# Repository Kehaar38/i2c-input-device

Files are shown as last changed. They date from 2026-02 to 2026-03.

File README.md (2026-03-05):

# I2C Input Device (ATmega328P)

## 概要
- ATmega328P を用いた I2C接続の入力デバイス
- 5ボタン＋ロータリーエンコーダーを搭載
- 差分式エンコーダ出力およびステータスビットを2バイト固定フォーマットで出力
- 動作テスト用デバイスも製作（[Test Device](#Test-Device-XIAO-ESP32S3)）

## 主な機能
- I2Cスレーブ
- 2バイト固定レスポンス
- 差分式エンコーダー

## 出力
I2C 応答フォーマット（Read 2 bytes）
- Byte0: エンコーダー差分（int8_t）
  - 前回 Read 以降の差分
    - -128..127 に飽和（超えたら status=001 を立てる）
    - Read したタイミングで累積差分を 0 にリセット（差分式）

- Byte1: 上位3bit=ステータス, 下位5bit=ボタン押下（押下で1）
  - bit0: center
  - bit1: up
  - bit2: right
  - bit3: down
  - bit4: left
  - status:
    - 000 = 正常
    - 001 = overflow

## ハード構成
- ATmega328P (3.3V, internal 8MHz)
- 5x tactile switch
- 12/15 encoder

## 写真
外観

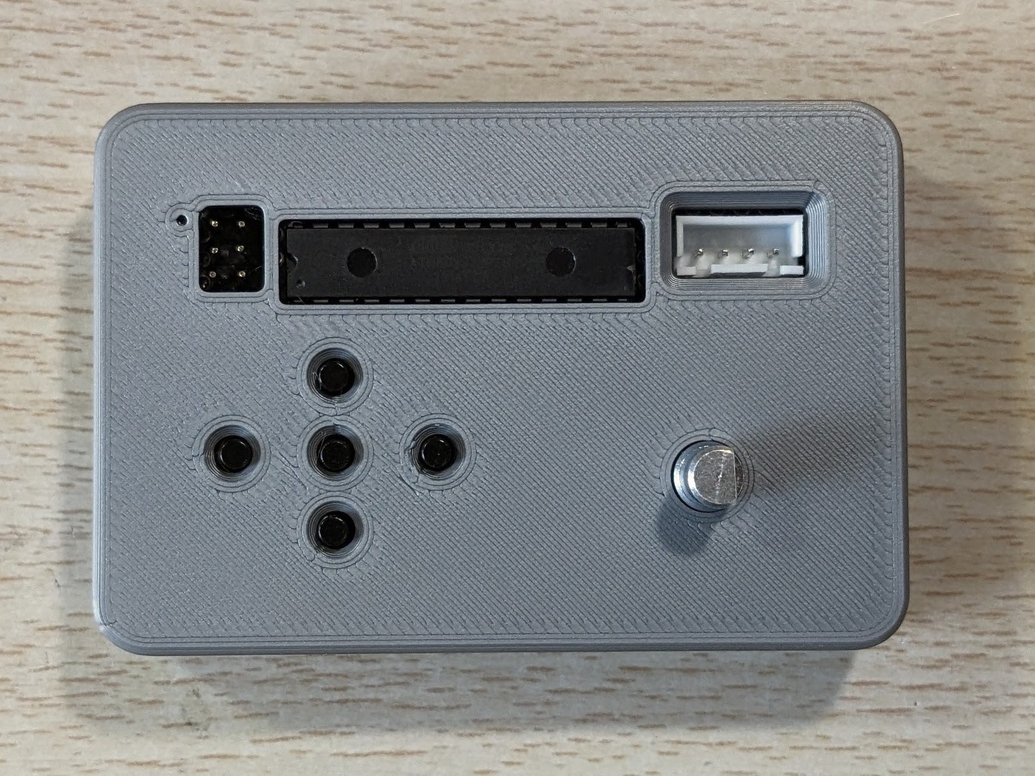
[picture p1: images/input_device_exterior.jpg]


基板

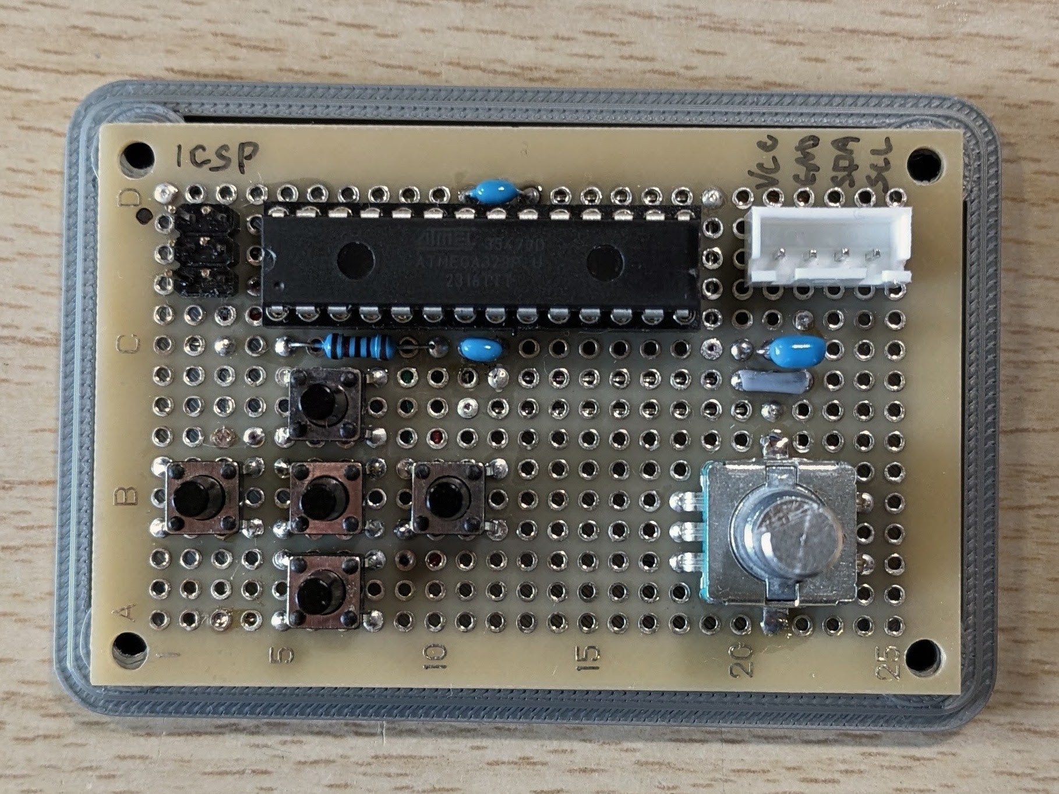
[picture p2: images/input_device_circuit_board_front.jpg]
基板表

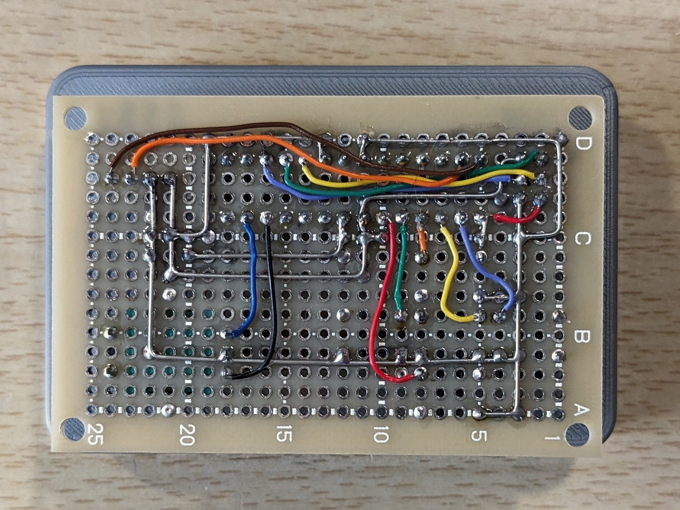
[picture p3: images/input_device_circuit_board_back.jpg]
基板裏


回路図

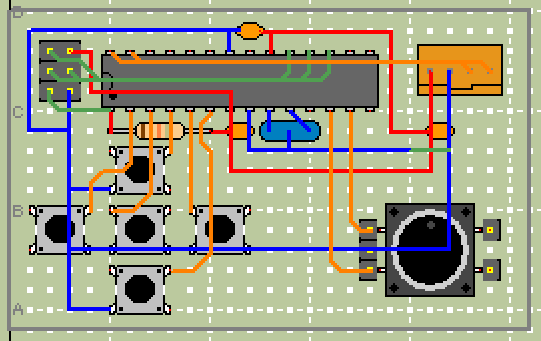
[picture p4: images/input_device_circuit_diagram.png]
回路図


## コーディング
ほぼ全部ChatGPT5.2に書いてもらっています。

## ビルド方法
### 開発環境
- Arduino IDE 2.3.7
- ボードパッケージ: ATmega328（MiniCore）
- 書き込み方式: Arduino as ISP
- ターゲット: ATmega328P（3.3V / 内部8MHz）

### ボード設定
- ボード: ATmega328
- Variant: 328P / 328PA
- Clock: Internal 8 MHz
- Bootloader: No bootloader
- BOD: BOD 2.7V
- EEPROM: EEPROM retained
- Compiler LTO: LTO enabled

### Fuse値
|Fuse|値|意味|
|---|---|---|
|L|E2|内部8MHz、CKDIV8無効|
|H|DA|SPI有効、BOOT無効|
|E|FD|BOD有効|

### I2C動作条件
- 電源: 3.3V
- クロック: 100kHz
- I2Cアドレス: 0x12
- 外部プルアップ抵抗はマスター側に実装

### 補足
- attachInterrupt は使用せず、PCINT を使用している
- onRequest 内で割り込み状態を変更しないこと
- ENC_STEPS_PER_NOTCH はエンコーダ個体に応じて調整すること

### 禁止事項
**書き込み装置とマスターの同時接続は禁止**  
特に書き込み装置とマスターのロジックレベルが異なる場合、電源ラインの逆流やI/Oピンへの過電圧などが生じてデバイスが破損する可能性がある。
- 書き込み時は必ずマスター側を取り外すこと
- 運用時は ISP ケーブルを接続しないこと

---

# Test Device (XIAO ESP32S3)

## 概要
- I2C Input Deviceの出力をテストするデバイス
- ボタンの押下状況とエンコーダーの累積値を表示する

## ハード構成
- XIAO ESP32S3
- 128x64 OLED (SSD1306 Driver)

## コーディング
全部ChatGPT5.2に書いてもらっています。

## 写真
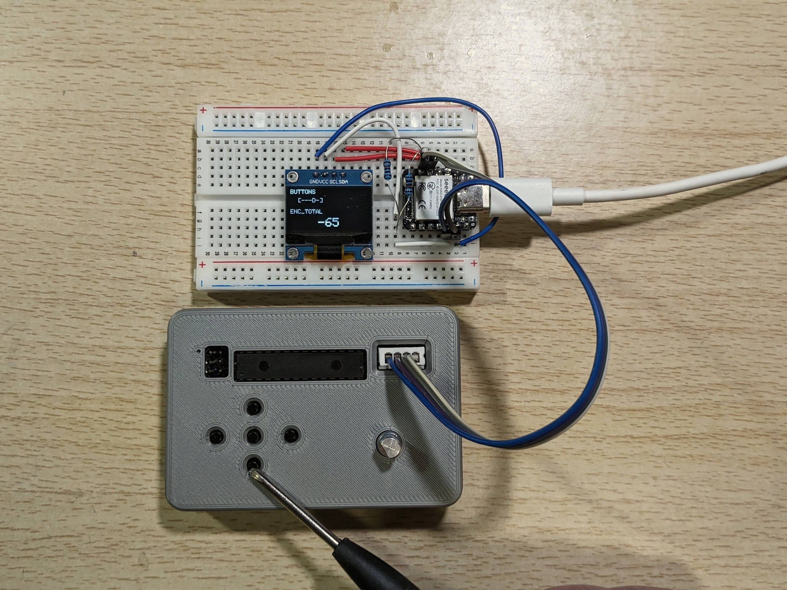
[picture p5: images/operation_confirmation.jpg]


---

## License Notices

Third-party license and notice information is available here:

- `THIRD_PARTY_NOTICES.md`
- `licenses/`

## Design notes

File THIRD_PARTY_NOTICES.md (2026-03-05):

# Third-Party Notices

This repository uses third-party libraries via Arduino cores and Arduino libraries.

## Included notice files

- `licenses/Adafruit_GFX_BSD-2-Clause.txt`
- `licenses/Adafruit_SSD1306_BSD-3-Clause.txt`
- `licenses/Adafruit_BusIO_MIT.txt`
- `licenses/LGPL-2.1.txt`

## Libraries used by this project

### firmware/input_device

- Library: Wire (I2C/TWI)
- Source: Arduino core (MiniCore AVR 3.1.2)
- License: GNU LGPL v2.1 or later (per `Wire.h` header)

### firmware/test_device

- Library: Wire (I2C/TWI)
- Source: ESP32 Arduino core 3.3.7
- License: GNU LGPL v2.1 or later (per `Wire.h` header)

- Library: Adafruit GFX Library 1.12.4
- Source: [Adafruit/Adafruit-GFX-Library](https://github.com/adafruit/Adafruit-GFX-Library)
- License: BSD (see `licenses/Adafruit_GFX_BSD-2-Clause.txt`)

- Library: Adafruit SSD1306 2.5.16
- Source: [Adafruit/Adafruit_SSD1306](https://github.com/adafruit/Adafruit_SSD1306)
- License: BSD (see `licenses/Adafruit_SSD1306_BSD-3-Clause.txt`)

- Dependency: Adafruit BusIO 1.17.4
- Source: [Adafruit/Adafruit_BusIO](https://github.com/adafruit/Adafruit_BusIO)
- License: MIT (see `licenses/Adafruit_BusIO_MIT.txt`)

## Notes

- This repository currently distributes source code and design files; compiled binaries are not distributed.
- If binary distribution starts in the future, include this file and `licenses/` alongside the distributed artifacts.

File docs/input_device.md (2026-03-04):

# ATmega328P (DIP) ピンアサイン
```
                            ATmega328P
                            -----------
    RESET / VCC via R - PC6|1    U   28|PC5 - SCL
             BTN_LEFT - PD0|2        27|PC4 - SDA
           BTN_CENTER - PD1|3        26|PC3 - NC
               BTN_UP - PD2|4        25|PC2 - NC
            BTN_RIGHT - PD3|5        24|PC1 - NC
             BTN_DOWN - PD4|6        23|PC0 - NC
DECAP3 / DECAP1 / VCC - VCC|7        22|GND - GND / DECAP2
DECAP3 / DECAP1 / GND - GND|8        21|AREF - NC
         NC(for XTAL) - PB6|9        20|AVCC - DECAP2
         NC(for XTAL) - PB7|10       19|PB5 - SCK
                   NC - PD5|11       18|PB4 - MISO
                ENC_A - PD6|12       17|PB3 - MOSI
                ENC_B - PD7|13       16|PB2 - NC
                   NC - PB0|14       15|PB1 - NC
                            -----------
```

## 接続
|ピン番号|機能|接続|
|---|---|---|
|1|RESET|PC6 --- J2 --- 10kR --- VCC|
|2|DIGITAL|PD0 --- BTN_LEFT ---GND|
|3|DIGITAL|PD1 --- BTN_CENTER --- GND|
|4|DIGITAL|PD2 --- BTN_UP --- GND|
|5|DIGITAL|PD3 --- BTN_RIGHT --- GND|
|6|DIGITAL|PD4 --- BTN_DOWN --- GND|
|7|VCC|VCC --- (0.1uF to GND) --- (4.7uF to GND) --- J1 --- J2|
|8|GND|GND --- J1 --- J2 --- ENC_C|
|9|(XTAL)|PB6 --- NC|
|10|(XTAL)|PB7 --- NC|
|11|-|PD5 --- NC|
|12|PCINT|PD6 --- ENC_A|
|13|PCINT|PD7 --- ENC_B|
|14|-|PB0 --- NC|
|15|-|PB1 --- NC|
|16|-|PB2 --- NC|
|17|MOSI|PB3 --- J2|
|18|MISO|PB4 --- J2|
|19|SCK|PB5 --- J2|
|20|AVCC|AVCC --- (0.1uF to GND) --- VCC|
|21|-|AREF --- NC|
|22|GND|GND --- GND|
|23|-|PC0 --- NC|
|24|-|PC1 --- NC|
|25|-|PC2 --- NC|
|26|-|PC3 --- NC|
|27|SDA|PC4 --- J1|
|28|SCL|PC5 --- J1|

J1 = マスター接続ピン (VCC, GND, SDA, SCL)  
J2 = ICSPピン

## 配線イメージ
回路図

# 部品リスト
- ATmega328P (DIP)
- ICソケット
- ロータリーエンコーダ
- 5 * タクトスイッチ
- 4.7uF コンデンサ
- 2 * 0.1uF コンデンサ
- 10kΩ 抵抗
- 4ピン JST XH ポスト
- 2x3 ピンヘッダ
- セラロック (任意)
- ユニバーサル基板 秋月Cタイプ

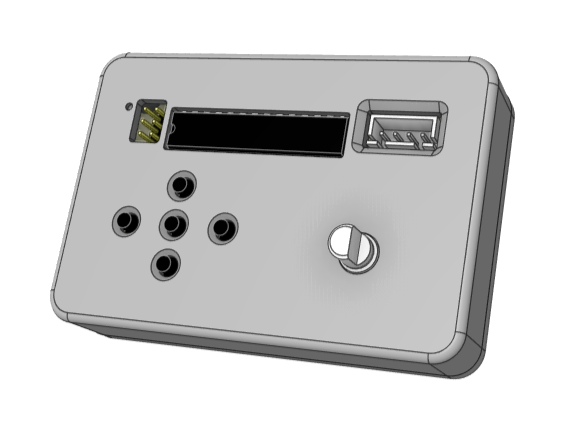
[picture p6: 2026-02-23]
images/input_device_3D_model.png

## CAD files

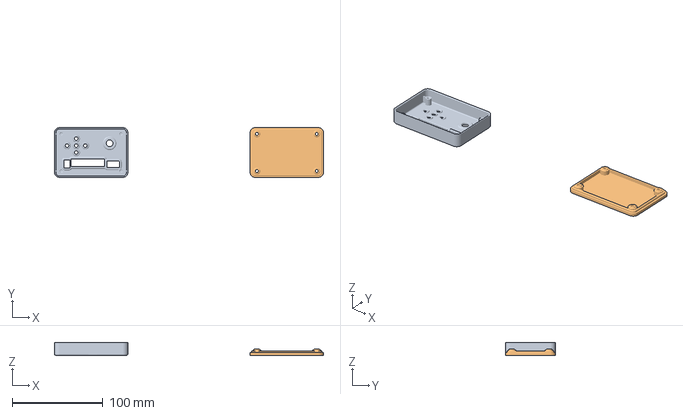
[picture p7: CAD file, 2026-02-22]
hardware/input_device_case/v1.3mf
297.0 x 55.0 x 14.1 mm
アッパーv1.stl
ロワーv1.stl

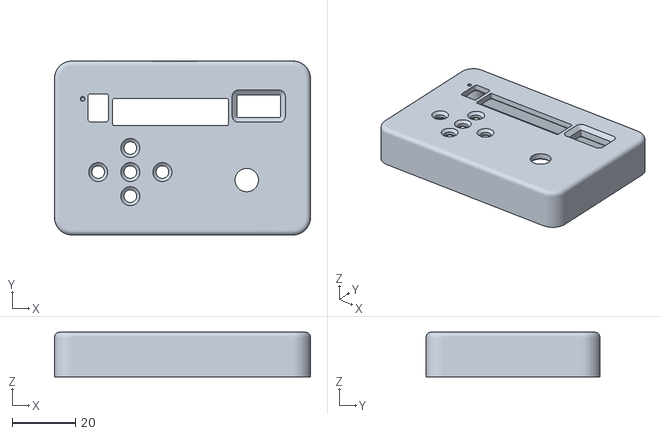
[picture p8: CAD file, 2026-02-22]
hardware/input_device_case/アッパーv1.stl
81.0 x 55.0 x 14.1

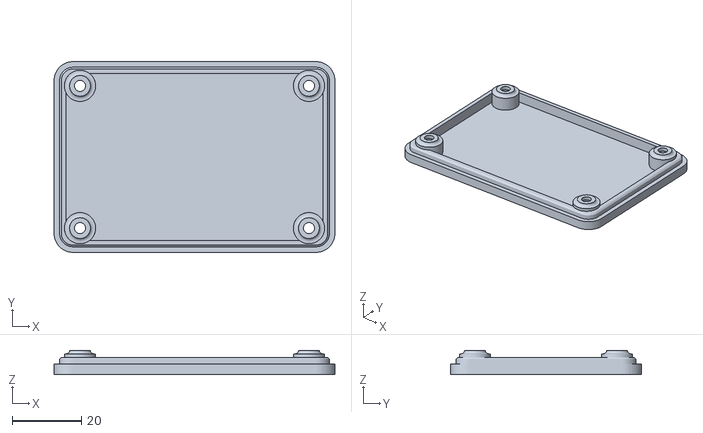
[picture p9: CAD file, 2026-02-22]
hardware/input_device_case/ロワーv1.stl
81.0 x 55.0 x 7.00

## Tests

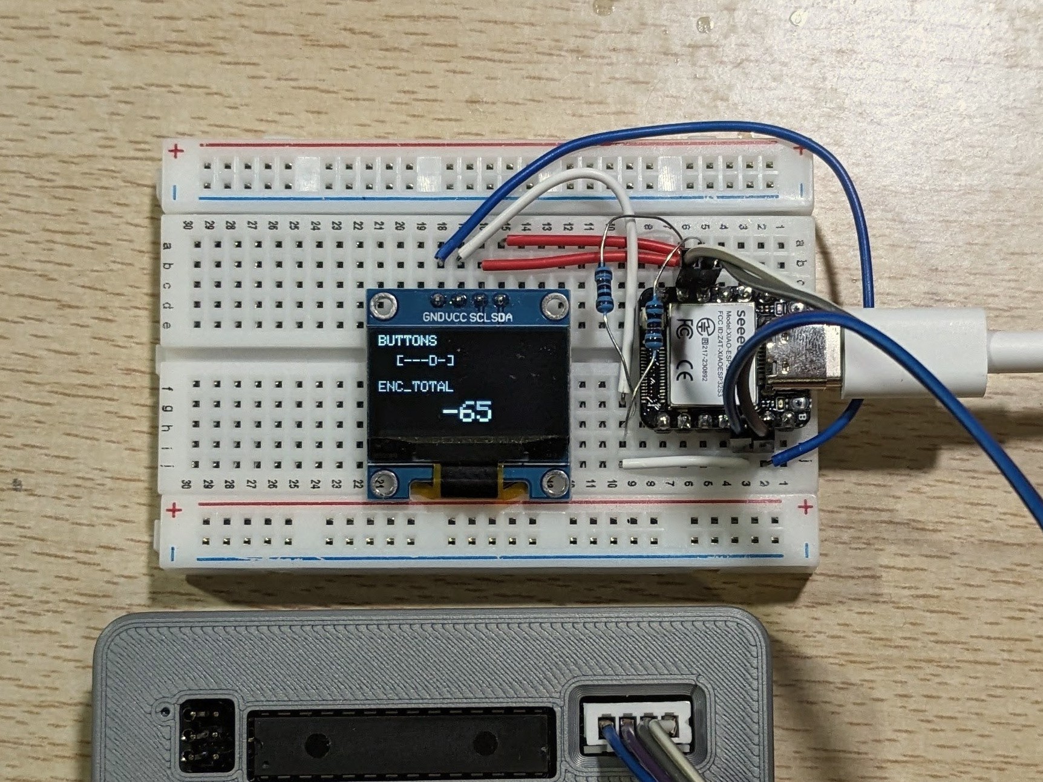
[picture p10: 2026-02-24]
images/test_device_exterior.jpg

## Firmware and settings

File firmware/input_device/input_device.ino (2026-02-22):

/*
  InputDevice (ATmega328P, 3.3V, internal 8MHz)
  - I2C スレーブとして、入力状態を 2バイト固定で返す
  - ボタン 5個 + ロータリーエンコーダ（A/B, スイッチ無し）

  I2C 応答フォーマット（Read 2 bytes）
    Byte0: enc_delta (int8_t)
      - 前回 Read 以降の差分
      - -128..127 に飽和（超えたら status=001 を立てる）
      - Read したタイミングで g_encAcc を 0 にリセット（差分式）

    Byte1: 上位3bit=status, 下位5bit=buttons
      bit0: center
      bit1: up
      bit2: right
      bit3: down
      bit4: left
      status:
        000 = 正常
        001 = overflow（飽和/内部飽和などの異常を検出）
*/

#include <Arduino.h>
#include <Wire.h>

#include <util/atomic.h>
#include <avr/interrupt.h>

// ================================
// ユーザー設定
// ================================
static const uint8_t I2C_ADDR = 0x12;

// ボタン（INPUT_PULLUP）
// 物理的には「押すとGNDへ落ちる」
// 出力（ビットマスク）は「押下=1」に揃える
static const uint8_t PIN_BTN_CENTER = PD1;
static const uint8_t PIN_BTN_UP     = PD2;
static const uint8_t PIN_BTN_RIGHT  = PD3;
static const uint8_t PIN_BTN_DOWN   = PD4;
static const uint8_t PIN_BTN_LEFT   = PD0;

// エンコーダ（A/B, INPUT_PULLUP）
static const uint8_t PIN_ENC_A = PD6; // PCINT22
static const uint8_t PIN_ENC_B = PD7; // PCINT23

// 1クリック（カチッ）あたりの「有効遷移数」
// エンコーダ個体によって 1/2/4 等があるので、実測で合わせる。
static const int8_t ENC_STEPS_PER_NOTCH = 2;

// 右回りを + にしたい場合 true（符号反転）
// もし逆だったら false にするだけでOK
static const bool ENC_DIR_REVERSE = true;

// ボタンのサンプリング周期（ms）
static const uint16_t BTN_SAMPLE_MS = 1;

// ================================
// 共有状態（ISR + I2C）
// ================================
// エンコーダ：差分累積（Readしたら0にリセット）
volatile int16_t g_encAcc = 0;

// エンコーダ：クリック換算前の途中経過（クォドラチャステップ）
// ※ これを I2C Read 毎に 0 にすると、ゆっくり回した時に反応しなくなるので保持する
volatile int8_t g_qstepAcc = 0;

// status（3bit）: 000=OK, 001=overflow
volatile uint8_t g_status3 = 0;

// ボタン（5bit, 押下=1）
volatile uint8_t g_btnMask5 = 0;

// ================================
// ヘルパ
// ================================
static inline void set_overflow_flag() {
  g_status3 = 0x01; // 001
}

static inline int8_t clamp_i16_to_i8(int16_t v, bool &clamped) {
  if (v > 127)  { clamped = true; return 127; }
  if (v < -128) { clamped = true; return -128; }
  clamped = false;
  return (int8_t)v;
}

// g_encAcc を int16 範囲で飽和加算（wrap防止）
static inline void encAcc_add_saturating(int16_t delta) {
  int32_t tmp = (int32_t)g_encAcc + (int32_t)delta;
  if (tmp > 32767) {
    g_encAcc = 32767;
    set_overflow_flag();
  } else if (tmp < -32768) {
    g_encAcc = -32768;
    set_overflow_flag();
  } else {
    g_encAcc = (int16_t)tmp;
  }
}

// ================================
// エンコーダ：クォドラチャデコード（PCINT）
// ================================
volatile uint8_t g_prevAB = 0;

static inline uint8_t readAB() {
  uint8_t a = (uint8_t)digitalRead(PIN_ENC_A);
  uint8_t b = (uint8_t)digitalRead(PIN_ENC_B);
  return (uint8_t)((a << 1) | b);
}

// A/Bの状態遷移から +1/-1 のクォドラチャステップを生成する
// 不正遷移（チャタ/ノイズ）は 0 扱いで捨てる
static inline int8_t quadrature_step(uint8_t prevAB, uint8_t currAB) {
  const uint8_t t = (uint8_t)((prevAB << 2) | currAB);

  // 0..15 の遷移に対するステップ（標準Gray系列前提）
  static const int8_t stepTable[16] = {
     0, -1, +1,  0,
    +1,  0,  0, -1,
    -1,  0,  0, +1,
     0, +1, -1,  0
  };

  int8_t s = stepTable[t];

  // 回転方向の符号を反転（右回りを + に合わせたい時に使う）
  if (ENC_DIR_REVERSE) s = (int8_t)-s;

  return s;
}

// PCINTが来たらA/B変化を1回処理する
void isr_encoder_change() {
  const uint8_t curr = readAB();
  const uint8_t prev = g_prevAB;
  g_prevAB = curr;

  int8_t qstep = quadrature_step(prev, curr);
  if (qstep == 0) return;

  // クリック換算用にクォドラチャステップを累積
  g_qstepAcc = (int8_t)(g_qstepAcc + qstep);

  // クリック単位（±1）へ変換
  if (ENC_STEPS_PER_NOTCH > 0) {
    while (g_qstepAcc >= ENC_STEPS_PER_NOTCH) {
      g_qstepAcc -= ENC_STEPS_PER_NOTCH;
      encAcc_add_saturating(+1);
    }
    while (g_qstepAcc <= -ENC_STEPS_PER_NOTCH) {
      g_qstepAcc += ENC_STEPS_PER_NOTCH;
      encAcc_add_saturating(-1);
    }
  }
}

// Port D（PCINT[23:16]）のピン変化割り込み
ISR(PCINT2_vect) {
  isr_encoder_change();
}

// ================================
// ボタン：簡易デバウンス（8サンプルのシフトレジスタ）
// ================================
struct Debounce8 {
  uint8_t hist = 0xFF;      // pullup=1 なので未押下を 1 とする
  bool stablePressed = false;

  void update(bool pinHigh) {
    hist = (uint8_t)((hist << 1) | (pinHigh ? 1 : 0));
    if (hist == 0x00) stablePressed = true;   // 連続0 -> 押下安定
    else if (hist == 0xFF) stablePressed = false; // 連続1 -> 未押下安定
  }
};

Debounce8 db_center, db_up, db_right, db_down, db_left;

// 押下状態を 5bit にパック（押下=1）
static inline uint8_t packButtons5() {
  uint8_t m = 0;
  if (db_center.stablePressed) m |= (1 << 0);
  if (db_up.stablePressed)     m |= (1 << 1);
  if (db_right.stablePressed)  m |= (1 << 2);
  if (db_down.stablePressed)   m |= (1 << 3);
  if (db_left.stablePressed)   m |= (1 << 4);
  return m;
}

static inline void updateButtonsDebounced() {
  db_center.update(digitalRead(PIN_BTN_CENTER));
  db_up.update(digitalRead(PIN_BTN_UP));
  db_right.update(digitalRead(PIN_BTN_RIGHT));
  db_down.update(digitalRead(PIN_BTN_DOWN));
  db_left.update(digitalRead(PIN_BTN_LEFT));

  const uint8_t m = packButtons5();

  // g_btnMask5 はISRからも参照され得るので、原子更新にする
  ATOMIC_BLOCK(ATOMIC_RESTORESTATE) {
    g_btnMask5 = m;
  }
}

// ================================
// I2C：Read要求が来たら 2バイト返す
// ================================
void onI2CRequest() {
  int16_t encSnap;
  uint8_t btnSnap;
  uint8_t stSnap;

  // 共有変数をスナップショットし、必要なものだけクリアする
  ATOMIC_BLOCK(ATOMIC_RESTORESTATE) {
    encSnap = g_encAcc;
    g_encAcc = 0;     // 差分式：読んだら0にする
    // g_qstepAcc は保持（途中経過を捨てない）
    btnSnap = g_btnMask5;
    stSnap  = g_status3;
    g_status3 = 0;    // statusは読んだらクリア（必要なら保持方式に変更可）
  }

  // encSnap を int8 に飽和
  bool clamped = false;
  int8_t encOut = clamp_i16_to_i8(encSnap, clamped);
  if (clamped) stSnap = 0x01; // overflow

  const uint8_t out0 = (uint8_t)encOut;
  const uint8_t out1 = (uint8_t)(((stSnap & 0x07) << 5) | (btnSnap & 0x1F));

  Wire.write(out0);
  Wire.write(out1);
}

// ================================
// setup / loop
// ================================
uint32_t lastBtnMs = 0;

void setup() {
  // ボタン入力
  pinMode(PIN_BTN_CENTER, INPUT_PULLUP);
  pinMode(PIN_BTN_UP,     INPUT_PULLUP);
  pinMode(PIN_BTN_RIGHT,  INPUT_PULLUP);
  pinMode(PIN_BTN_DOWN,   INPUT_PULLUP);
  pinMode(PIN_BTN_LEFT,   INPUT_PULLUP);

  // エンコーダ入力
  pinMode(PIN_ENC_A, INPUT_PULLUP);
  pinMode(PIN_ENC_B, INPUT_PULLUP);
  g_prevAB = readAB();

  // PCINT（Port D）を有効化：PD6/PD7（PCINT22/23）
  PCICR  |= (1 << PCIE2);
  PCMSK2 |= (1 << PCINT22);
  PCMSK2 |= (1 << PCINT23);

  // I2Cスレーブ開始
  Wire.begin(I2C_ADDR);
  Wire.onRequest(onI2CRequest);

  // デバウンス初期化（短時間で安定状態に寄せる）
  for (int i = 0; i < 16; i++) {
    updateButtonsDebounced();
    delay(1);
  }
  lastBtnMs = millis();
}

void loop() {
  // ボタンは一定周期で更新
  const uint32_t now = millis();
  if ((uint32_t)(now - lastBtnMs) >= BTN_SAMPLE_MS) {
    lastBtnMs = now;
    updateButtonsDebounced();
  }
}

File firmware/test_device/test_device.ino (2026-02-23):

#include <Wire.h>
#include <Adafruit_GFX.h>
#include <Adafruit_SSD1306.h>

// ================================
// I2C Config
// ================================
static const uint8_t I2C_ADDR_INPUT = 0x12;     // InputDevice (ATmega) I2C address
static const uint8_t I2C_ADDR_OLED  = 0x3C;     // SSD1306 OLED address

static const int I2C_SDA_PIN = 5;               // XIAO ESP32-S3 D4 = GPIO5
static const int I2C_SCL_PIN = 6;               // XIAO ESP32-S3 D5 = GPIO6
static const uint32_t I2C_FREQ = 100000;        // 100kHz

// Polling interval
static const uint32_t POLL_MS = 50;

// ================================
// OLED Config
// ================================
#define SCREEN_WIDTH  128
#define SCREEN_HEIGHT 64
#define OLED_RESET    -1
Adafruit_SSD1306 display(SCREEN_WIDTH, SCREEN_HEIGHT, &Wire, OLED_RESET);

// OLED更新周期（頻繁に更新しすぎるとちらつくので控えめに）
static const uint32_t OLED_UPDATE_MS = 100;

// ================================
// Protocol / Buttons
// Byte1 low 5 bits = buttons (pressed=1)
// bit0:center, bit1:up, bit2:right, bit3:down, bit4:left
// Byte1 high 3 bits = status (000 OK, 001 OVF)
// ================================
enum ButtonBits : uint8_t {
  BTN_CENTER = 1 << 0,
  BTN_UP     = 1 << 1,
  BTN_RIGHT  = 1 << 2,
  BTN_DOWN   = 1 << 3,
  BTN_LEFT   = 1 << 4,
};

// 長押し判定（ms）
static const uint32_t LONG_PRESS_MS = 800;

// ================================
// Helpers (Serial)
// ================================
static void printButtons(uint8_t b5) {
  Serial.print("buttons[");
  Serial.print((b5 & BTN_CENTER) ? "C" : "-");
  Serial.print((b5 & BTN_UP)     ? "U" : "-");
  Serial.print((b5 & BTN_RIGHT)  ? "R" : "-");
  Serial.print((b5 & BTN_DOWN)   ? "D" : "-");
  Serial.print((b5 & BTN_LEFT)   ? "L" : "-");
  Serial.print("] ");
}

static void printBinary5(uint8_t b5) {
  for (int i = 4; i >= 0; --i) Serial.print((b5 >> i) & 1);
}

static void printStatus(uint8_t st3) {
  Serial.print("status=");
  Serial.print(st3, DEC);
  if (st3 == 0) Serial.print("(OK)");
  else if (st3 == 1) Serial.print("(OVF)");
  else Serial.print("(UNK)");
}

// ================================
// Helpers (OLED)
// ================================
static void makeButtonsString(char out[8], uint8_t b5) {
  // 表示例: [--R--]
  // 並び: C U R D L
  out[0] = '[';
  out[1] = (b5 & BTN_CENTER) ? 'C' : '-';
  out[2] = (b5 & BTN_UP)     ? 'U' : '-';
  out[3] = (b5 & BTN_RIGHT)  ? 'R' : '-';
  out[4] = (b5 & BTN_DOWN)   ? 'D' : '-';
  out[5] = (b5 & BTN_LEFT)   ? 'L' : '-';
  out[6] = ']';
  out[7] = '\0';
}

static void drawCenteredText(int16_t y, const String &text, uint8_t textSize) {
  display.setTextSize(textSize);
  display.setTextColor(SSD1306_WHITE);

  int16_t x1, y1;
  uint16_t w, h;
  display.getTextBounds(text, 0, y, &x1, &y1, &w, &h);
  int16_t x = (SCREEN_WIDTH - (int16_t)w) / 2;
  if (x < 0) x = 0;
  display.setCursor(x, y);
  display.print(text);
}

static void updateOLED(uint8_t buttons5, int32_t encTotal) {
  char btnStr[8];
  makeButtonsString(btnStr, buttons5);

  display.clearDisplay();

  // 見出し
  display.setTextSize(1);
  display.setTextColor(SSD1306_WHITE);

  display.setCursor(0, 0);
  display.println("BUTTONS");

  display.setCursor(0, 14);
  display.print("  ");
  display.println(btnStr);

  display.setCursor(0, 32);
  display.println("ENC_TOTAL");

  // 数値は中央に大きめで表示
  drawCenteredText(46, String(encTotal), 2);

  display.display();
}

// ================================
// Main
// ================================
void setup() {
  Serial.begin(115200);
  delay(300);

  Serial.println();
  Serial.println("InputDevice I2C Reader (XIAO ESP32-S3)");
  Serial.println("Reading 2 bytes: [enc_delta(int8), status3+buttons5]");
  Serial.printf("I2C(Input)=0x%02X  OLED=0x%02X  SDA(GPIO%d) SCL(GPIO%d) freq=%lu\n",
                I2C_ADDR_INPUT, I2C_ADDR_OLED, I2C_SDA_PIN, I2C_SCL_PIN, (unsigned long)I2C_FREQ);

  Wire.begin(I2C_SDA_PIN, I2C_SCL_PIN);
  Wire.setClock(I2C_FREQ);

  // OLED init
  if (!display.begin(SSD1306_SWITCHCAPVCC, I2C_ADDR_OLED)) {
    Serial.println("SSD1306 allocation failed");
    while (true) delay(100);
  }
  display.clearDisplay();
  display.display();
}

// ================================
// Loop
// ================================
void loop() {
  static uint32_t lastPollMs = 0;
  static uint32_t lastOledMs = 0;

  // 前回値（変化検出用）
  static int8_t  lastEncDelta = 0;
  static uint8_t lastByte1 = 0;

  // ロータリー累積（合計）
  static int32_t encTotal = 0;

  // センター長押し判定用
  static bool centerPrevPressed = false;
  static uint32_t centerPressStartMs = 0;
  static bool longPressFired = false;

  uint32_t now = millis();
  if (now - lastPollMs < POLL_MS) return;
  lastPollMs = now;

  // 2バイト読む
  int n = Wire.requestFrom((int)I2C_ADDR_INPUT, 2);
  if (n < 2 || Wire.available() < 2) {
    Serial.println("I2C read failed: not enough bytes (check wiring/address/pullups)");
    while (Wire.available()) (void)Wire.read();
    return;
  }

  uint8_t b0 = Wire.read();
  uint8_t b1 = Wire.read();

  int8_t encDelta = (int8_t)b0;
  uint8_t buttons5 = b1 & 0x1F;
  uint8_t status3  = (b1 >> 5) & 0x07;

  // delta を累積
  if (encDelta != 0) encTotal += (int32_t)encDelta;

  // センターボタン長押しで encTotal リセット
  bool centerPressed = (buttons5 & BTN_CENTER) != 0;

  if (centerPressed && !centerPrevPressed) {
    // 押し始め
    centerPressStartMs = now;
    longPressFired = false;
  } else if (!centerPressed && centerPrevPressed) {
    // 離した
    longPressFired = false;
  }

  if (centerPressed && !longPressFired) {
    if (now - centerPressStartMs >= LONG_PRESS_MS) {
      encTotal = 0;
      longPressFired = true;

      Serial.println("enc_total reset (CENTER long press)");
    }
  }

  centerPrevPressed = centerPressed;

  // Serial出力（変化がある時だけ）
  bool changed = (encDelta != 0) || (b1 != lastByte1) || (encDelta != lastEncDelta) || (status3 != 0);
  if (changed) {
    Serial.print("enc_delta=");
    Serial.print(encDelta);

    Serial.print("  enc_total=");
    Serial.print(encTotal);

    Serial.print("  ");
    printStatus(status3);
    Serial.print("  ");
    printButtons(buttons5);
    Serial.print("bits=");
    printBinary5(buttons5);
    Serial.print("  raw=[");
    Serial.printf("%02X %02X", b0, b1);
    Serial.println("]");
  }

  // OLEDは一定周期で更新（変化が無くても追従する）
  if (now - lastOledMs >= OLED_UPDATE_MS) {
    lastOledMs = now;
    updateOLED(buttons5, encTotal);
  }

  lastEncDelta = encDelta;
  lastByte1 = b1;
}

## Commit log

2026-02-19 概要、構成の追加
2026-02-20 インデント修正
2026-02-22 ピンアサイン確定
2026-02-22 修正。ボタンは動くようになったけどエンコーダーは無反応。デバイス起因。
2026-02-22 テストデバイス用コード、回路図
2026-02-22 テストデバイス
2026-02-22 .lstファイルは除外する
2026-02-22 エンコーダーが動くようになった。ゆっくり動かすと反応しない。
2026-02-22 3Dプリントファイル
    [v1.3mf, アッパーv1.stl, ロワーv1.stl]
2026-02-22 ディレクトリ変更
2026-02-22 ブラッシュアップ、日本語コメント追加
2026-02-22 モデル修正
    [v1.3mf, アッパーv1.stl]
2026-02-22 イメージ追加
2026-02-23 写真の追加
2026-02-23 enc_total追加
2026-02-23 I2Cディスプレイ表示機能追加
2026-02-23 テストデバイス写真
2026-02-23 写真更新
2026-02-24 ファイル名変更
2026-03-04 Enhance README with Test Device information
    Updated the README to include a link to the Test Device section and added details about the Test Device's functionality and hardware configuration.
2026-03-04 Document ATmega328P pin assignment and connections
    Added pin assignment, connection details, wiring image, and parts list for ATmega328P.
